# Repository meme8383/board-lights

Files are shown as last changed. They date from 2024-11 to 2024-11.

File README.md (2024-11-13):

# Meepo V3S ARGB Power & Control PCB
Schematic for Meepo V3S Skateboard Lights. Meant to power [these 24V WS2811 COB Leds](https://www.aliexpress.us/item/3256805848873454.html?gatewayAdapt=glo2usa) using the Meepo V3S 36V Battery and [wled firmware](https://kno.wled.ge/).

https://github.com/user-attachments/assets/10e10ca3-55f4-4bfa-9f18-f33567d93a93

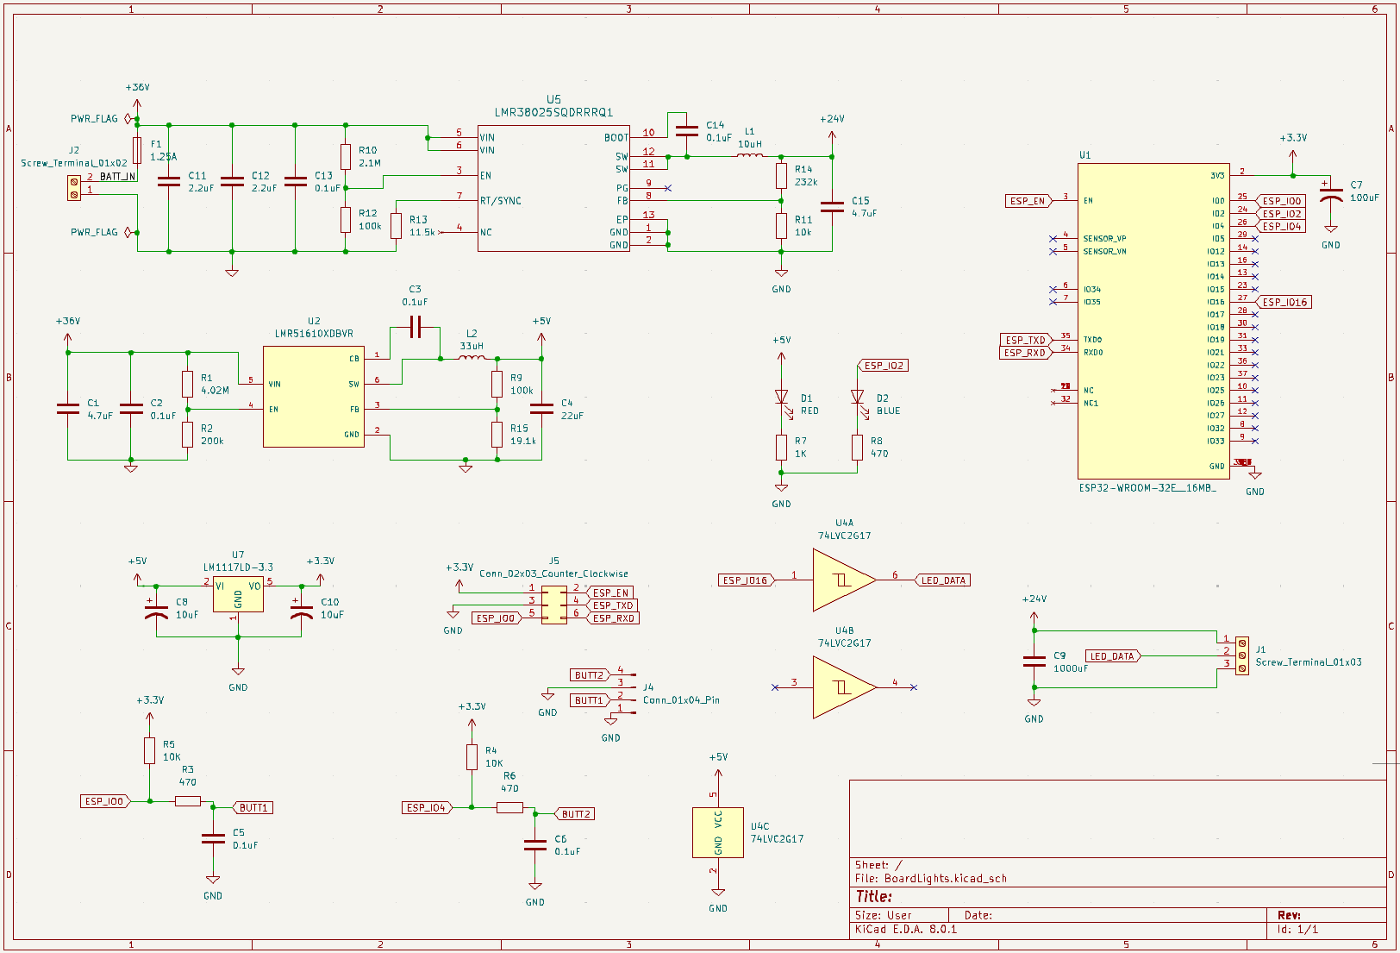
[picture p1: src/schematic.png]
schematic


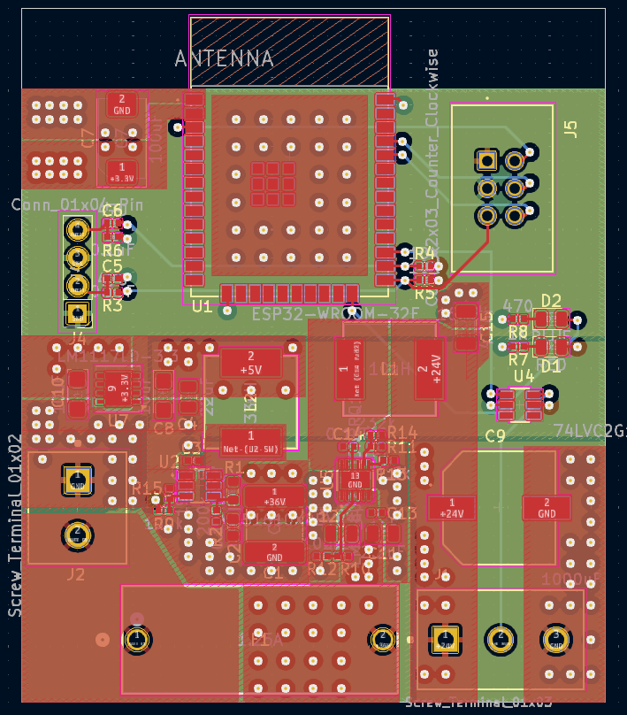
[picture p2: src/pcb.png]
pcb


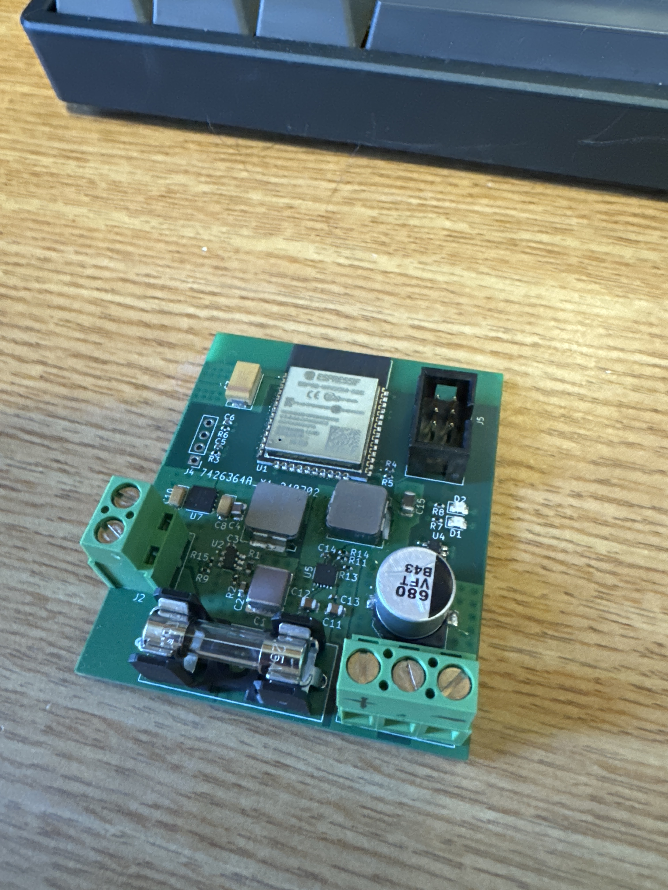
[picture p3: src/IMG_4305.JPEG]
board


## Known issues
This was my first real PCB project, so there were many (easily fixable) issues, but it still works as-is.
- Did not pull EN high (whoops). Bridge the two upper pins of the connector after the board is powered on.
- ESP-Prog connector is mirrored (whoops again).
- The output capacitor I planned to use did not support 24V. There is a capacitor with the same footprint and lower capacitance but higher max voltage that I used instead. Let me know if you want the full BOM.
- There is no power switch. I intented to use an inline waterproof switch on the connector, but it would have been nice to be able to disable the board without unplugging it or pulling the fuse.
- There are no holes (or space for them) to connect it to a mount.
- Level shifter did not work. I just bridged the pins and it works fine.

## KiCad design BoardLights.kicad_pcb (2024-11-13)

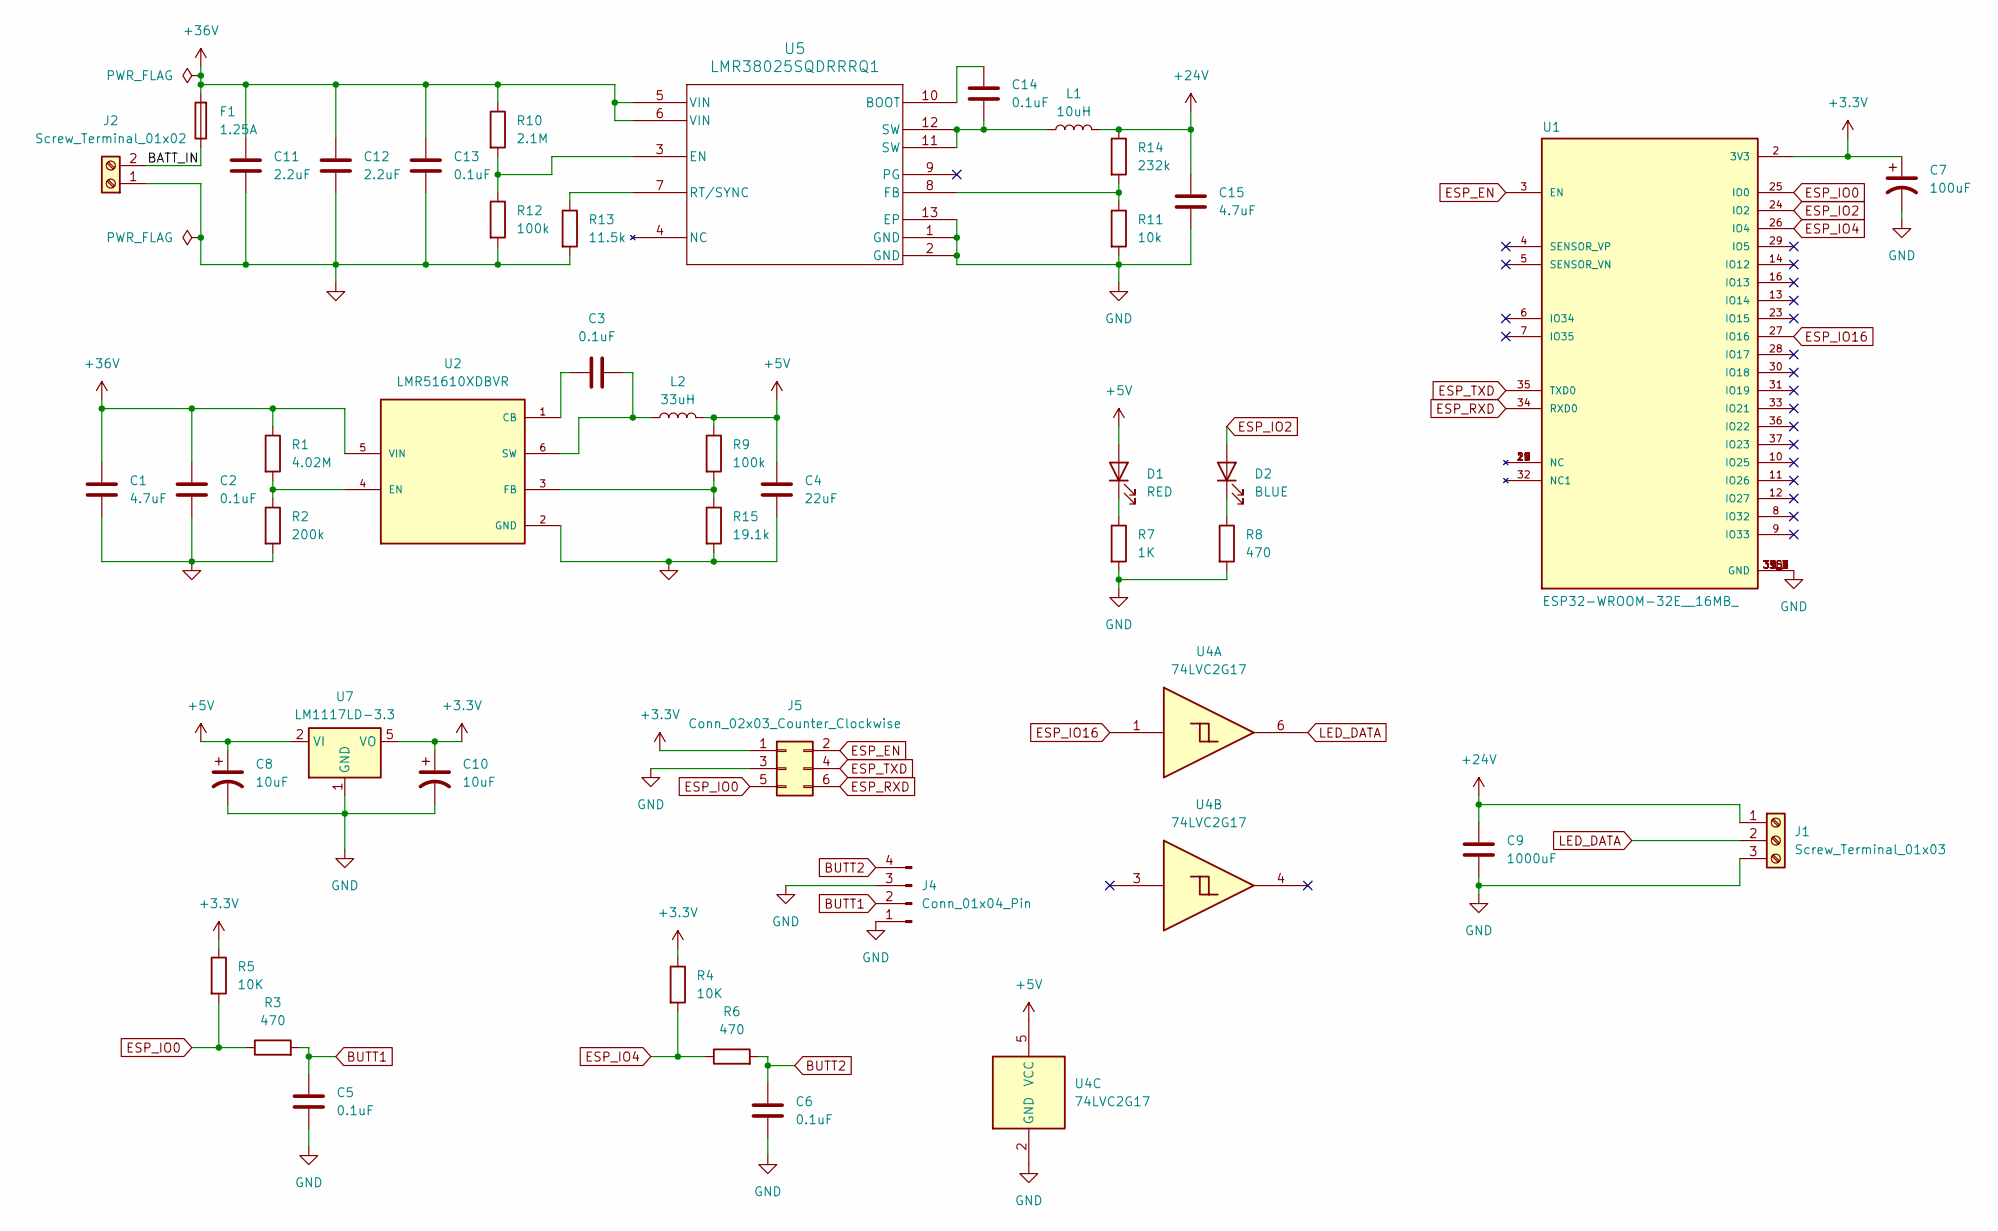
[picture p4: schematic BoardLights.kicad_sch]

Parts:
C1: 4.7uF; C_2220_5750Metric
C2: 0.1uF; C_0603_1608Metric
C3, C5, C6, C13, C14: 0.1uF; C_0402_1005Metric
C4: 22uF; C_0805_2012Metric
C7: 100uF; CP_EIA-7343-31_Kemet-D
C8, C10: 10uF; CP_EIA-3216-18_Kemet-A
C9: 1000uF; CAP_EEEFT1C102AP
C11, C12: 2.2uF; C_0805_2012Metric
C15: 4.7uF; C_1206_3216Metric
D1: RED; LED_0805_2012Metric
D2: BLUE; LED_0805_2012Metric
F1: 1.25A; FUSE_65600001009_LTF
J1: Screw_Terminal_01x03; TE_282841-3
J2: Screw_Terminal_01x02; TE_282841-2
J4: Conn_01x04_Pin; PinHeader_1x04_P2.54mm_Vertical
J5: Conn_02x03_Counter_Clockwise; TE_1761681-1
L1: 10uH; IND_IHLP-3232DZ_VIS
L2: 33uH; IND_IHLP-3232DZ_VIS
R1: 4.02M; R_0603_1608Metric
R2: 200k; R_0402_1005Metric
R3, R6, R8: 470; R_0402_1005Metric
R4, R5: 10K; R_0402_1005Metric
R7: 1K; R_0402_1005Metric
R9, R12: 100k; R_0402_1005Metric
R10: 2.1M; R_0402_1005Metric
R11: 10k; R_0402_1005Metric
R13: 11.5k; R_0402_1005Metric
R14: 232k; R_0402_1005Metric
R15: 19.1k; R_0402_1005Metric
U1: ESP32-WROOM-32E__16MB_; XCVR_ESP32-WROOM-32E__16MB_; PARTREV 1.4
U2: LMR51610XDBVR; SOT95P280X145-6N; PARTREV B
U4: 74LVC2G17; SOT95P280X145-6N
U5: LMR38025SQDRRRQ1; WSON12_DRR_TEX
U7: LM1117LD-3.3; DFN400X400X80-9N

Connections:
+3.3V: C7.1, C10.1, J5.1, R4.1, R5.1, U1.2 (3V3), U7.5 (VO), U7.6 (VO), U7.7 (VO), U7.9 (VO)
+5V: C4.2, C8.1, D1.2 (A), L2.2, R9.1, U4.5 (VCC), U7.2 (VI), U7.3 (VI), U7.4 (VI)
+24V: C9.1, C15.1, J1.1, L1.2, R14.1
+36V: C1.1, C2.1, C11.1, C12.1, C13.1, F1.2, R1.1, R10.1, U2.5 (VIN), U5.5 (VIN), U5.6 (VIN)
/BATT_IN: F1.1, J2.2
BUTT1: C5.1, J4.2, R3.2
BUTT2: C6.1, J4.4, R6.2
ESP_EN: J5.2, U1.3 (EN)
ESP_IO0: J5.5, R3.1, R5.2, U1.25 (IO0)
ESP_IO2: D2.2 (A), U1.24 (IO2)
ESP_IO4: R4.2, R6.1, U1.26 (IO4)
ESP_IO16: U1.27 (IO16), U4.1
ESP_RXD: J5.6, U1.34 (RXD0)
ESP_TXD: J5.4, U1.35 (TXD0)
GND: C1.2, C2.2, C4.1, C5.2, C6.2, C7.2, C8.2, C9.2, C10.2, C11.2, C12.2, C13.2, C15.2, J1.3, J2.1, J4.1, J4.3, J5.3, R2.2, R7.2, R8.2, R11.2, R12.2, R13.2, R15.2, U1.1 (GND), U1.15 (GND), U1.38 (GND), U1.39_1 (GND), U1.39_2 (GND), U1.39_3 (GND), U1.39_4 (GND), U1.39_5 (GND), U1.39_6 (GND), U1.39_7 (GND), U1.39_8 (GND), U1.39_9 (GND), U2.2 (GND), U4.2 (GND), U5.1 (GND), U5.2 (GND), U5.13 (EP), U7.1 (GND)
LED_DATA: J1.2, U4.6
unnamed: C14.2, L1.1, U5.11 (SW), U5.12 (SW)
unnamed: D1.1 (K), R7.1
unnamed: D2.1 (K), R8.1
unnamed: C3.1, U2.1 (CB)
unnamed: R1.2, R2.1, U2.4 (EN)
unnamed: R9.2, R15.1, U2.3 (FB)
unnamed: C3.2, L2.1, U2.6 (SW)
unnamed: C14.1, U5.10 (BOOT)
unnamed: R10.2, R12.1, U5.3 (EN)
unnamed: R11.1, R14.2, U5.8 (FB)
unnamed: R13.1, U5.7 (RT/SYNC)

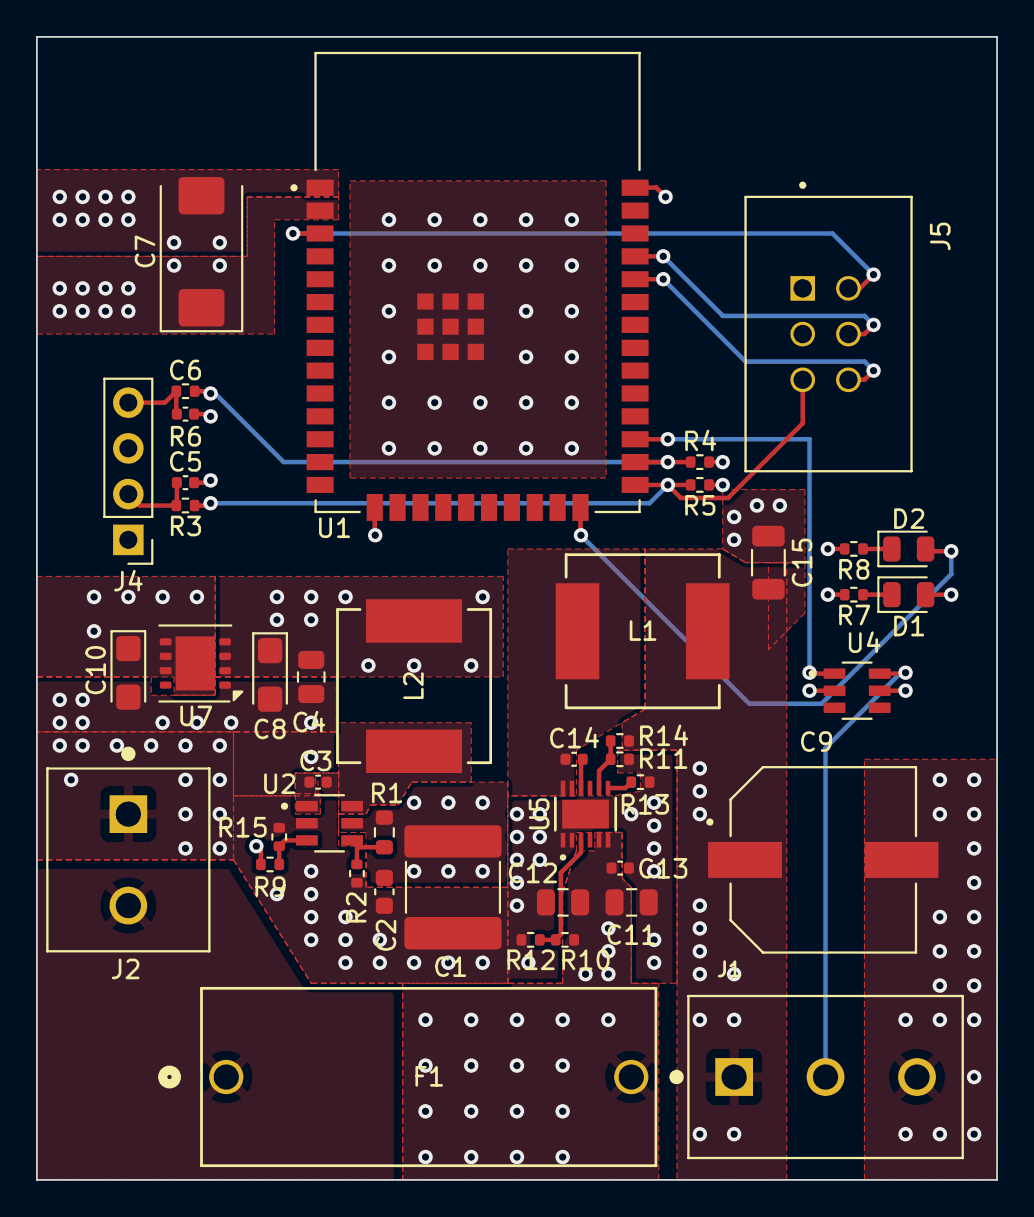
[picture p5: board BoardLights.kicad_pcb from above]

Board: 4 copper layers, 53.3 x 63.5 mm, 44 parts (0 on the bottom side), 27 nets.
